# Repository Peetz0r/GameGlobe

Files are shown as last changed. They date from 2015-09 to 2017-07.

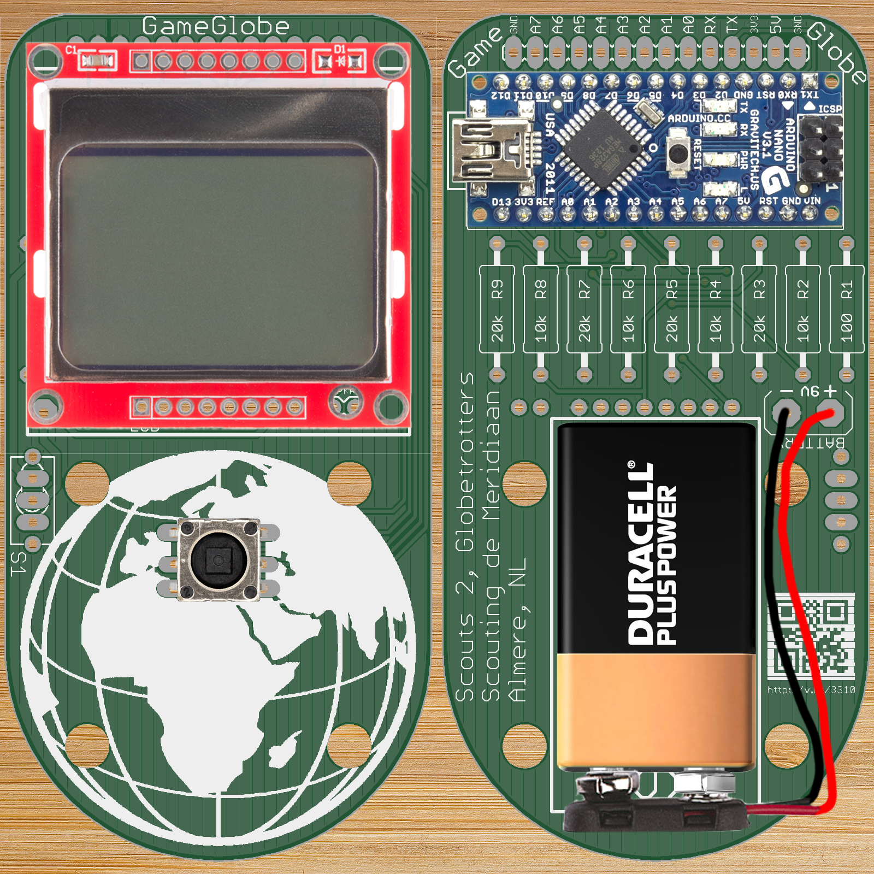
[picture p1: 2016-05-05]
pcb/gameglobe.png

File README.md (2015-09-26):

# GameGlobe
GameGlobe cheap handheld game console, Arduino based

# Bill Of Materials
Part			|  Price	|  Amount	|  Cost p.p.	|  Link
------------------------|--------------:|--------------:|--------------:|------------------------------
PCB			|  $28,00	|    20		|  $1,40	|  http://dirtypcbs.com/
Arduino Nano		|  $ 1,87	|     1		|  $1,87	|  http://www.aliexpress.com/item//32242060255.html
3310 display		|  $ 3,07	|     2		|  $1,54	|  http://www.aliexpress.com/item//32438248013.html
9V clip			|  $ 1,25	|    20		|  $0,06	|  http://www.aliexpress.com/item//32353434826.html
D-Pad (SKQUCAA010)	|  $10,93	|    20		|  $0,55	|  http://www.aliexpress.com/item//32354178656.html
Power switch		|  $ 3,50	|   100		|  $0,04	|  http://www.aliexpress.com/item//32390211893.html
Speaker			|  $ 6,18	|    50		|  $0,13	|  http://www.aliexpress.com/item//32438430293.html
Resistors		|    free	|  many		|   free	|  

Total $5,43

Note: somehow 20 boards is cheaper per piece than 30. So we'll buy 40 (2*20).
And the displays have some shipping costs (but they are the cheapest regardless).

Note: check all of the parts for hidden shippig costs when you order larger numbers.
It may be that a seller changes this without me knowing. Especially some of the Arduino sellers.

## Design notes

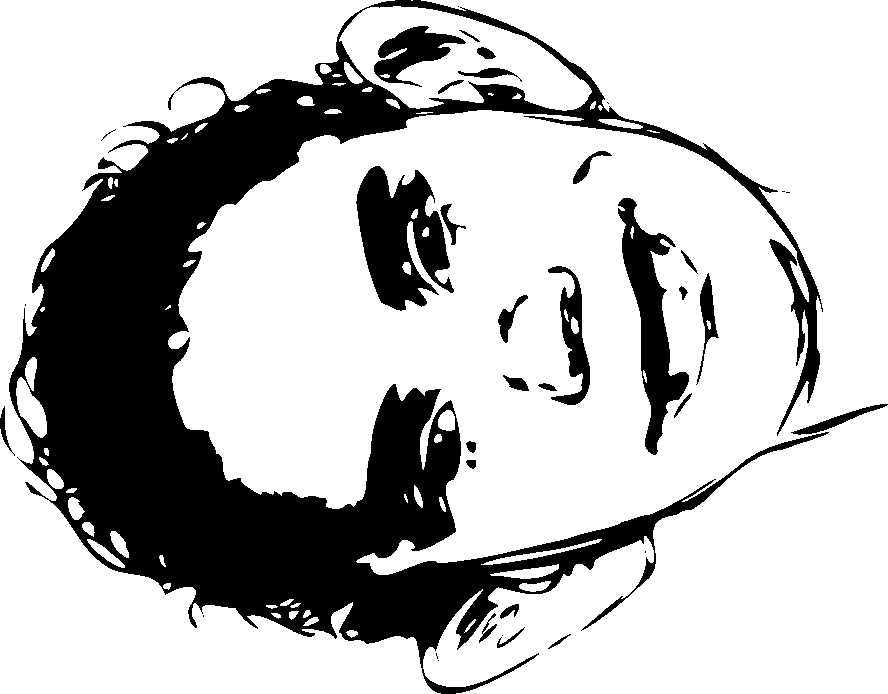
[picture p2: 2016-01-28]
pula-05-bw.bmp

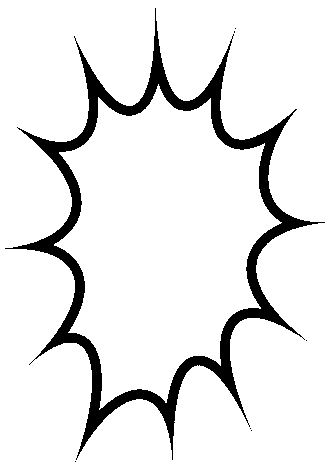
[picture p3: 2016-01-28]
boom.bmp

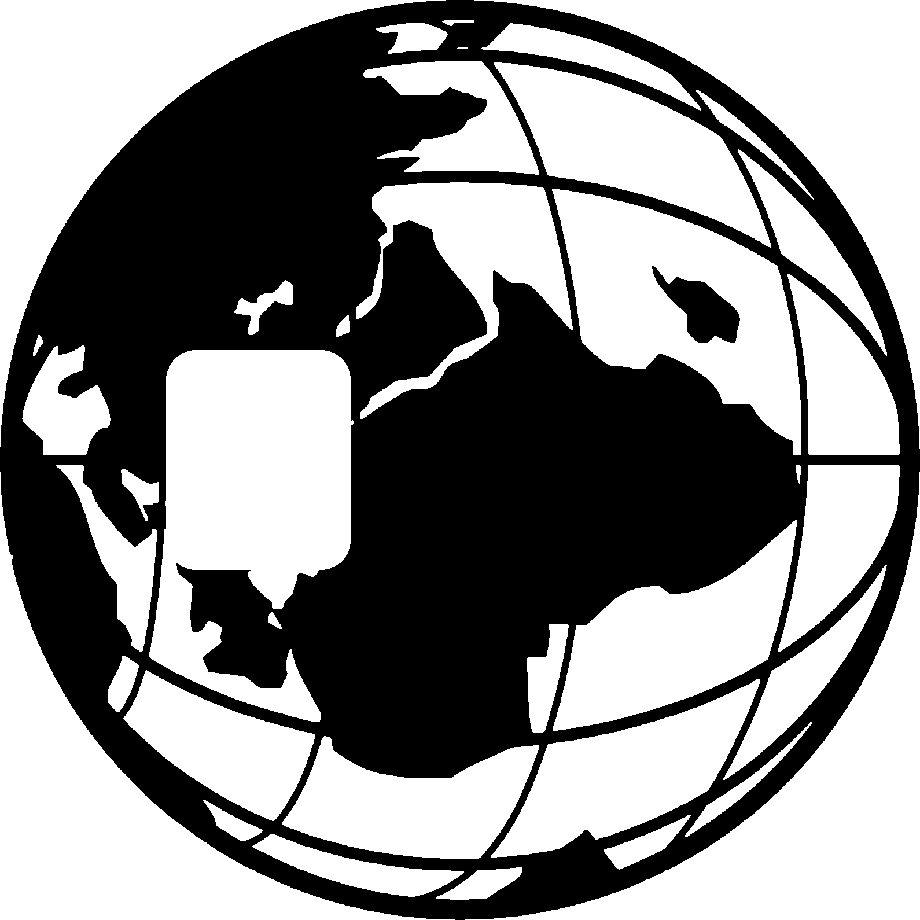
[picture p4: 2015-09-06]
wereldbol_silkscreen.bmp

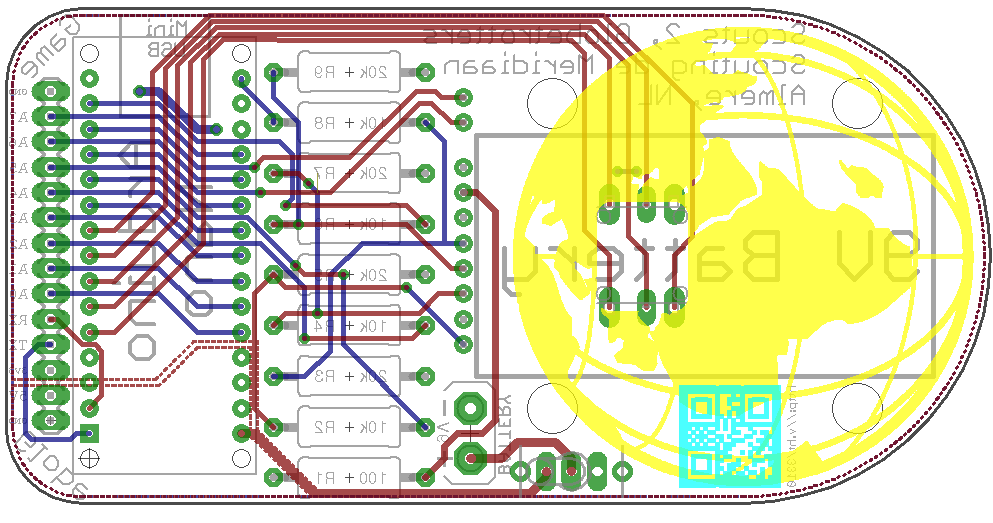
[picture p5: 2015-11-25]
pcb/pcb_layout.png

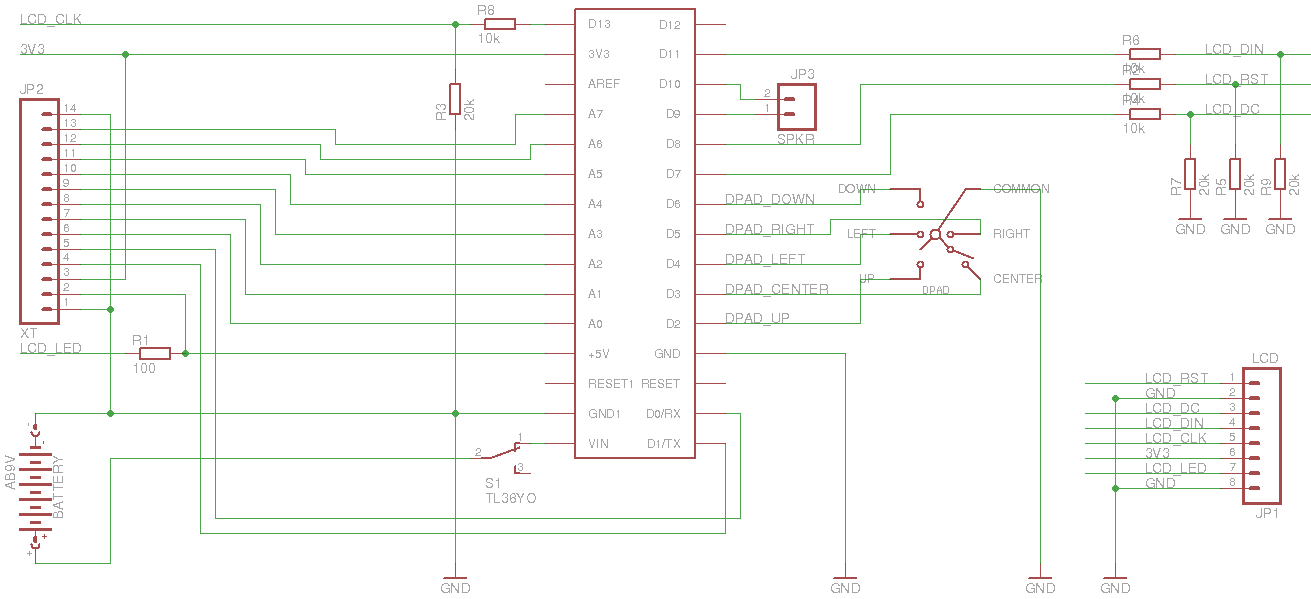
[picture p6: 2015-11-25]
pcb/schema.png

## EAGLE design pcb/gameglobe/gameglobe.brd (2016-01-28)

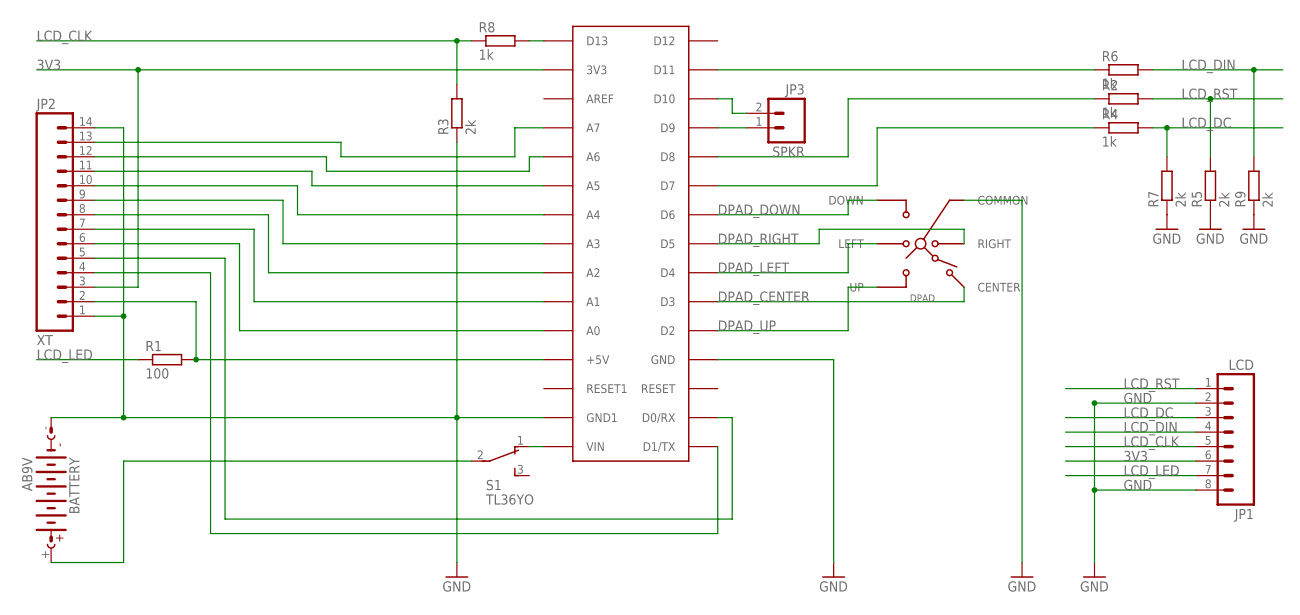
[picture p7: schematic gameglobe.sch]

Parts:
ARDUINO_NANO: ARDUINONANO; PDIP-32
BATTERY: AB9V
DPAD: SKQUCAA010; SKQU
JP1: LCD; 1X08_ROUND
JP2: XT; 1X14-LONGPADS
JP3: SPKR; 1X02
R1: 100; 0411/15
R2, R4, R6, R8: 1k; 0411/15
R3, R5, R7, R9: 2k; 0411/15
S1: TL36YO; TL3XYO

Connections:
3V3: ARDUINO_NANO.3V3, JP1.6, JP2.3
5V: ARDUINO_NANO.+5V, JP2.2, R1.2
A0: ARDUINO_NANO.A0, JP2.6
A1: ARDUINO_NANO.A1, JP2.7
A2: ARDUINO_NANO.A2, JP2.8
A3: ARDUINO_NANO.A3, JP2.9
A4: ARDUINO_NANO.A4, JP2.10
A5: ARDUINO_NANO.A5, JP2.11
A6: ARDUINO_NANO.A6, JP2.12
A7: ARDUINO_NANO.A7, JP2.13
DPAD_CENTER: ARDUINO_NANO.D3, DPAD.CENTER
DPAD_DOWN: ARDUINO_NANO.D6, DPAD.DOWN
DPAD_LEFT: ARDUINO_NANO.D4, DPAD.LEFT
DPAD_RIGHT: ARDUINO_NANO.D5, DPAD.RIGHT
DPAD_UP: ARDUINO_NANO.D2, DPAD.UP
GND: ARDUINO_NANO.GND, ARDUINO_NANO.GND1, BATTERY.-, DPAD.COMMON, JP1.2, JP1.8, JP2.1, JP2.14, R3.1, R5.1, R7.1, R9.1
LCD_CLK: JP1.5, R3.2, R8.1
LCD_DC: JP1.3, R4.2, R7.2
LCD_DIN: JP1.4, R6.2, R9.2
LCD_LED: JP1.7, R1.1
LCD_RST: JP1.1, R2.2, R5.2
unnamed: ARDUINO_NANO.D13, R8.2
unnamed: ARDUINO_NANO.D11, R6.1
unnamed: ARDUINO_NANO.D8, R2.1
unnamed: ARDUINO_NANO.D9, JP3.1
unnamed: ARDUINO_NANO.VIN, S1.1 (O)
unnamed: BATTERY.+, S1.2
unnamed: ARDUINO_NANO.D10, JP3.2
unnamed: ARDUINO_NANO.D7, R4.1
RX: ARDUINO_NANO.D0/RX, JP2.5
TX: ARDUINO_NANO.D1/TX, JP2.4

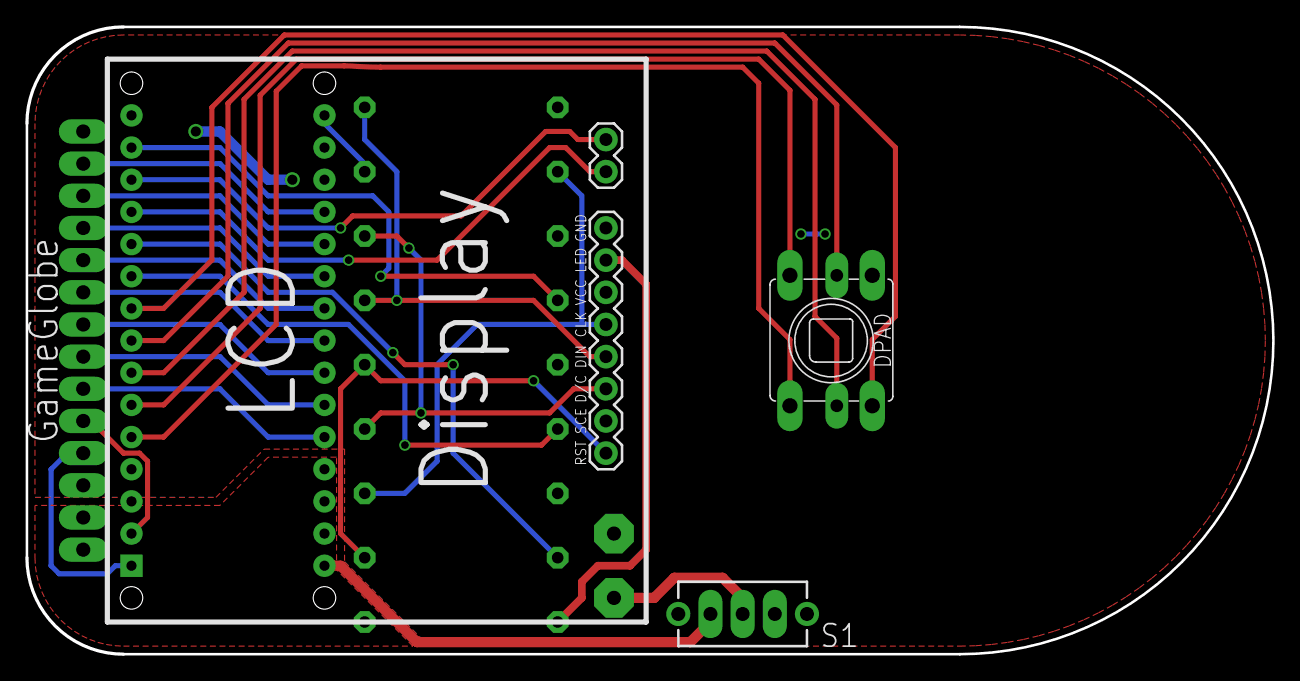
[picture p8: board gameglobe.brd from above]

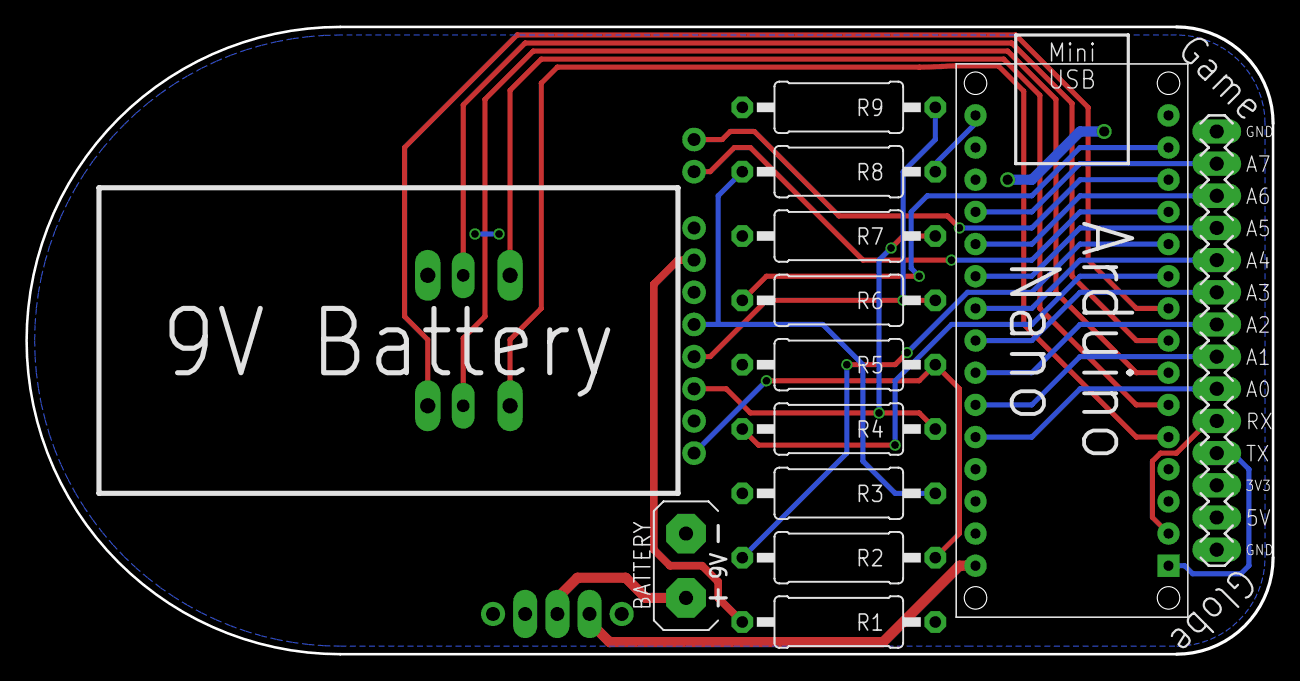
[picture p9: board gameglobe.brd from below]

Board: 2 copper layers, 98.4 x 49.5 mm, 16 parts (12 on the bottom side), 31 nets.

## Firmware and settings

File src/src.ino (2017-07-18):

#include "../lib/Adafruit-GFX-Library/Adafruit_GFX.h"
#include "../lib/Adafruit_PCD8544.h"
#include "../lib/Bounce2/Bounce2.h"
#include "../lib/arduino-toneac/toneAC.h"
#include <EEPROM.h>
#include "pitches.h"
#include "naam.h"

#define PIN_U 2
#define PIN_S 3
#define PIN_L 4
#define PIN_R 5
#define PIN_D 6

#define PIN_LCD_DC  7
#define PIN_LCD_RST 8

#define EEPROM_VOLUME 10
#define EEPROM_SNAKE 110
#define EEPROM_TETRIS 120
#define EEPROM_FLAPPY 130

Adafruit_PCD8544 d = Adafruit_PCD8544(PIN_LCD_DC, -1, PIN_LCD_RST);

Bounce b_u = Bounce();
Bounce b_d = Bounce();
Bounce b_l = Bounce();
Bounce b_r = Bounce();
Bounce b_s = Bounce();

enum game {
	MENU,
	SNAKE,
	TETRIS,
	FLAPPY,
	HIGHSCORES,
	GAME_OVER,
};

game current_game = MENU;
game previous_game;

int8_t selected = 0;
uint8_t volume;
uint8_t need_write_volume = 0;
uint8_t score;

uint8_t snake_length;
uint8_t snake_pos[255];
int8_t snake_food_x;
int8_t snake_food_y;
long snake_delay;
long snake_last_frame = 0;
enum direction {
	UP,
	DOWN,
	LEFT,
	RIGHT,
};
direction snake_direction = LEFT;
direction snake_direction_old = LEFT;

#define TETRIS_I1 0x00f0
#define TETRIS_I2 0x2222

#define TETRIS_J1 0x0047
#define TETRIS_J2 0x0322
#define TETRIS_J3 0x0071
#define TETRIS_J4 0x0113

#define TETRIS_L1 0x0017
#define TETRIS_L2 0x0223
#define TETRIS_L3 0x0074
#define TETRIS_L4 0x0311

#define TETRIS_O1 0x0033

#define TETRIS_S1 0x0036
#define TETRIS_S2 0x0231

#define TETRIS_T1 0x0027
#define TETRIS_T2 0x0232
#define TETRIS_T3 0x0072
#define TETRIS_T4 0x0131

#define TETRIS_Z1 0x0063
#define TETRIS_Z2 0x0132

uint8_t tetris_speed;
long tetris_delay;
long tetris_last_frame = 0;
uint16_t tetris_state[10];
int8_t tetris_tetromino_x;
int8_t tetris_tetromino_y;
uint16_t tetris_tetromino_shape;
uint16_t tetris_tetromino_next;

uint8_t flappy_x;
float flappy_y;
float flappy_y_speed;
int8_t flappy_pipe;
long flappy_delay;

void menu_loop() {
	d.clearDisplay();
	if(b_u.fell()) selected--;
	if(b_d.fell()) selected++;
	if(selected > 4) selected = 0;
	if(selected < 0) selected = 4;

	d.drawRoundRect(0,selected*9, 80,11, 5, 1);
	d.drawLine(1,selected*9+5, 6,selected*9+5, 1);
	d.fillTriangle(6,selected*9+3, 6,selected*9+7, 8,selected*9+5, 1);

	d.setCursor(11, 2);
	d.print("Snake");
	d.setCursor(11, 11);
	d.print("Tetris");
	d.setCursor(11, 20);
	d.print("FlappySmile");
	d.setCursor(11, 29);
	d.print("Highscores");
	d.setCursor(11, 38);

	d.print("Volume");
	d.drawRect(52,37,         24,9, 1);
	d.fillRect(54,39, (volume*2),5, 1);
	if(volume == 0) {
		d.drawLine(52,37, 75,45, 1);
		d.drawLine(52,45, 75,37, 1);
	}

	if(b_s.fell()) {
		toneAC(NOTE_A6, volume, 25);
		score = 0;
		if(selected == 0) {
			snake_length = 5;
			snake_pos[0] = 115;
			snake_pos[1] = 116;
			snake_pos[2] = 117;
			snake_pos[3] = 118;
			snake_pos[4] = 119;
			snake_delay = 350;
			snake_last_frame = 0;
			snake_direction = LEFT;
			snake_place_food();

			current_game = SNAKE;
		} else if(selected == 1) {
			tetris_state[0] = 0;
			tetris_state[1] = 0;
			tetris_state[2] = 0;
			tetris_state[3] = 0;
			tetris_state[4] = 0;
			tetris_state[5] = 0;
			tetris_state[6] = 0;
			tetris_state[7] = 0;
			tetris_state[8] = 0;
			tetris_state[9] = 0;

			tetris_speed = 1;
			tetris_delay = 500;
			tetris_last_frame = 0;

			current_game = TETRIS;
		} else if(selected == 2) {
			flappy_x = 0;
			flappy_y = 24;
			flappy_y_speed = 0;
			flappy_pipe = 12;
			flappy_delay = 50;

			current_game = FLAPPY;
		} else if(selected == 3) {
			current_game = HIGHSCORES;
		}
	}

	if(selected == 4) {
		if(b_l.fell()) {
			if(volume > 0) {
				volume--;
				need_write_volume = 1;
			}
			toneAC(NOTE_A6, volume, 25);
		}
		if(b_r.fell()) {
			if(volume < 10) {
				volume++;
				need_write_volume = 1;
			}
			toneAC(NOTE_A6, volume, 25);
		}
	} else if(need_write_volume == 1) {
		EEPROM.write(EEPROM_VOLUME, volume);
		need_write_volume = 0;
	}

	d.display();
	delay(25);
}

void snake_loop () {
	if(b_u.fell() && snake_direction_old != DOWN ) snake_direction = UP;
	if(b_d.fell() && snake_direction_old != UP   ) snake_direction = DOWN;
	if(b_l.fell() && snake_direction_old != RIGHT) snake_direction = LEFT;
	if(b_r.fell() && snake_direction_old != LEFT ) snake_direction = RIGHT;

	if((millis() - snake_last_frame) > snake_delay) {
		snake_direction_old = snake_direction;
		d.clearDisplay();

		for(uint8_t i = snake_length+1; i > 0; i--) {
			snake_pos[i] = snake_pos[i-1];
		}

		int8_t tmp_snake_x;
		int8_t tmp_snake_y;

		switch(snake_direction) {
			case UP:
				tmp_snake_x = (snake_pos[1]%21);
				tmp_snake_y = (snake_pos[1]/21)-1;
				break;
			case DOWN:
				tmp_snake_x = (snake_pos[1]%21);
				tmp_snake_y = (snake_pos[1]/21)+1;
				break;
			case LEFT:
				tmp_snake_x = (snake_pos[1]%21)-1;
				tmp_snake_y = (snake_pos[1]/21);
				break;
			case RIGHT:
				tmp_snake_x = (snake_pos[1]%21)+1;
				tmp_snake_y = (snake_pos[1]/21);
				break;
		}

		if(tmp_snake_x <  0) tmp_snake_x = 20;
		if(tmp_snake_x > 20) tmp_snake_x =  0;
		if(tmp_snake_y <  0) tmp_snake_y = 11;
		if(tmp_snake_y > 11) tmp_snake_y =  0;


		snake_pos[0] = tmp_snake_y*21 + tmp_snake_x;

		if(tmp_snake_x == snake_food_x && tmp_snake_y == snake_food_y) {
			snake_length++;
			snake_place_food();
			snake_delay *= 0.975; // snake difficulty

			toneAC(NOTE_G5, volume, 40); delay(20);
			toneAC(NOTE_G6, volume, 40);
		} else {
			toneAC(NOTE_A3, volume, 5);
		}

		for(uint8_t i = 0; i < snake_length; i++) {
			d.fillRoundRect((snake_pos[i]%21)*4, (snake_pos[i]/21)*4, 4, 4, 1, 1);
			if(i > 0 && tmp_snake_x == snake_pos[i]%21 && tmp_snake_y == snake_pos[i]/21) {
				score = snake_length;
				previous_game = SNAKE;
				game_over();
			}
		}
		d.drawRoundRect(snake_food_x*4, snake_food_y*4, 4, 4, 2, 1);
		d.display();

		snake_last_frame = millis();
	}
}

void snake_place_food() {
	boolean done = false;
	while(!done) {
		snake_food_x = random(20);
		snake_food_y = random(11);
		done = true;
		for(uint8_t i = 0; i < snake_length; i++) {
			if(snake_food_x == snake_pos[i]%21 && snake_food_y == snake_pos[i]/21) {
				done = false;
			}
		}
	}
}

uint16_t tetris_new_shape() {
	uint16_t shape;
	switch (random(7)) {
		case 0: shape = TETRIS_I1; break;
		case 1: shape = TETRIS_J1; break;
		case 2: shape = TETRIS_L1; break;
		case 3: shape = TETRIS_O1; break;
		case 4: shape = TETRIS_S1; break;
		case 5: shape = TETRIS_T1; break;
		case 6: shape = TETRIS_Z1; break;
	}
	for(int i = random(4); i >= 0; i--) {
		shape = tetris_rotate(shape);
	}
	return shape;
}

uint16_t tetris_rotate(uint16_t shape) {
	switch(shape) {
		case TETRIS_I1: return TETRIS_I2;
		case TETRIS_I2: return TETRIS_I1;

		case TETRIS_J1: return TETRIS_J2;
		case TETRIS_J2: return TETRIS_J3;
		case TETRIS_J3: return TETRIS_J4;
		case TETRIS_J4: return TETRIS_J1;

		case TETRIS_L1: return TETRIS_L2;
		case TETRIS_L2: return TETRIS_L3;
		case TETRIS_L3: return TETRIS_L4;
		case TETRIS_L4: return TETRIS_L1;

		case TETRIS_O1: return TETRIS_O1;

		case TETRIS_S1: return TETRIS_S2;
		case TETRIS_S2: return TETRIS_S1;

		case TETRIS_T1: return TETRIS_T2;
		case TETRIS_T2: return TETRIS_T3;
		case TETRIS_T3: return TETRIS_T4;
		case TETRIS_T4: return TETRIS_T1;

		case TETRIS_Z1: return TETRIS_Z2;
		case TETRIS_Z2: return TETRIS_Z1;
	}
}

void tetris_loop () {
	if((millis() - tetris_last_frame) > tetris_delay / tetris_speed) {

		toneAC(NOTE_A3, volume, 5);
		if(!tetris_tetromino_shape) {
			if(!tetris_tetromino_next) {
				tetris_tetromino_next = tetris_new_shape();
			}
			tetris_tetromino_shape = tetris_tetromino_next;
			tetris_tetromino_next = tetris_new_shape();
			tetris_tetromino_x = 4;
			tetris_tetromino_y = -1;
			tetris_speed = 1;
		}

		tetris_draw(0, 1);

		tetris_last_frame = millis();
	}

	if(b_d.fell()) {
		tetris_speed = 10;
	}
	if(b_d.rose()) {
		tetris_speed = 1;
	}

	if(b_l.fell()) {
		tetris_draw(-1, 0);
	}
	if(b_r.fell()) {
		tetris_draw(1, 0);
	}

	if(b_u.fell()) {
		tetris_tetromino_shape = tetris_rotate(tetris_tetromino_shape);
		tetris_draw(0, 0);
	}
}

void tetris_draw(int m_x, int m_y) {
	d.clearDisplay();
	d.drawRect(11, -1, 31, 49, 1);

	int tetris_move_ok = 1;

	for(int t_x = 0; t_x < 4; t_x++) {
		for(int t_y = 0; t_y < 4; t_y++) {
			if(tetris_tetromino_shape & (1 << (t_y*4+t_x))) {
				if(tetris_tetromino_y+m_y+t_y > 15
				 || (tetris_state[tetris_tetromino_x+m_x+t_x] >> tetris_tetromino_y+m_y+t_y) & 1
				 || tetris_tetromino_x+m_x+t_x > 9
				 || tetris_tetromino_x+m_x+t_x < 0) {

					 if(m_x == 0 && m_y == 0) {
						for(int i = 0; i < 3; i++) {
							tetris_tetromino_shape = tetris_rotate(tetris_tetromino_shape);
						}
					 }

					if(tetris_tetromino_y < 1) {
						previous_game = TETRIS;
						game_over();
						return;
					}

					if(m_y) {
						for(int x2 = 0; x2 < 4; x2++) {
							for(int y2 = 0; y2 < 4; y2++) {
								if(tetris_tetromino_shape & (1 << (y2*4+x2))) {
									tetris_state[tetris_tetromino_x+m_x+x2] |= 1 << (tetris_tetromino_y+y2);
								}
							}
						}
						tetris_tetromino_shape = 0;

						int points = 0;
						for(int i = 0; i < 16; i++) {
							int test = 1;
							for(int j = 0; j < 10; j++) {
								test &= (tetris_state[j] >> i) &1;
							}
							if(test) {
								if(!points) {
									points = 1;
								} else {
									points *= 2;
								}
								Serial.println(i);

								for(int j = 0; j < 10; j++) {
									uint16_t mask_r = (1 << i+1)-1;
									uint16_t mask_l = ~mask_r;
									tetris_state[j] = (tetris_state[j]&mask_l) | (tetris_state[j]&mask_r>>1) << 1;
								}

								i--;

								// beep!
								toneAC(NOTE_G5, volume, 40); delay(20);
								toneAC(NOTE_G6, volume, 40);
							}
						}
						score += points;

						tetris_delay *= 0.985; // tetris difficulty (should be closer to 1 than snake)

					}
					tetris_move_ok = 0;
				}
			}
		}
	}

	if(tetris_move_ok) {
		tetris_tetromino_x += m_x;
		tetris_tetromino_y += m_y;
	}

	for(int t_x = 0; t_x < 4; t_x++) {
		for(int t_y = 0; t_y < 4; t_y++) {
			if(tetris_tetromino_shape & (1 << (t_y*4+t_x))) {
				d.fillRect(12+(tetris_tetromino_x+t_x)*3, (tetris_tetromino_y+t_y)*3, 2, 2, 1);
			}
		}
	}

	for(int x = 0; x < 10; x++) {
		for(int y = 0; y < 16; y++) {
			if(tetris_state[x] & (1 << y)) {
					d.fillRect(12+x*3, y*3, 2, 2, 1);
			}
		}
	}

	for(int t_x = 0; t_x < 4; t_x++) {
		for(int t_y = 0; t_y < 4; t_y++) {
			if(tetris_tetromino_next & (1 << (t_y*4+t_x))) {
				d.fillRect(60+t_x*3, 6+t_y*3, 2, 2, 1);
			}
		}
	}

	d.setCursor(49, 26);
	d.print("Score");
	d.setCursor(55, 36);
	d.print(score);

	d.display();
}

void flappy_loop () {
	flappy_y += flappy_y_speed;

	// generate new pipes once in a while
	if(flappy_x > 120) {
		flappy_x = 0;
		flappy_pipe = random(24);
	}

	// change vertical acceleration over time
	if(flappy_y_speed < 0) {
		// when moving up, decelerate quickly
		flappy_y_speed += 0.2;
	} else {
		// when falling down, accelerate less quickly
		flappy_y_speed += 0.075;
	}

	// (re)set vertical acceleration on button push
	if(b_u.fell()) {
		flappy_y_speed = -2;
	}

	// collision checking
	if(flappy_y > 47 ||
	  ((flappy_x > 52 && flappy_x < 68) &&
	  (flappy_y < flappy_pipe+8 || flappy_y > flappy_pipe+20))) {
		previous_game = FLAPPY;
		game_over();
	}

	if(flappy_x == 70) {
		score++;
		flappy_delay *= 0.975;
	}

	flappy_x++;

	d.clearDisplay();

	// pipes, narrow part
	d.fillRect(100-flappy_x, 0, 10, flappy_pipe, 1); // upper
	d.fillRect(100-flappy_x, flappy_pipe+28, 10, 100, 1); // lower

	// pipes, wide part (edge)
	d.fillRect(100-flappy_x-2, flappy_pipe-2, 14, 4, 1); // upper
	d.fillRect(100-flappy_x-2, flappy_pipe+26, 14, 4, 1); // lower

	d.drawCircle(42, flappy_y-1, 5, 1); // face
	d.fillRect(39, flappy_y-3, 2, 2, 1); // left eye
	d.fillRect(44, flappy_y-3, 2, 2, 1); // right eye
	d.drawLine(39, flappy_y, 41, flappy_y+2, 1); // left part of smile
	d.drawPixel(42, flappy_y+2, 1); // center part of smile
	d.drawLine(43, flappy_y+2, 45, flappy_y, 1); // right part of smile
	d.display();

	delay(flappy_delay);
}

void game_over() {
	current_game = GAME_OVER;

	toneAC(NOTE_G6, volume, 50);
	toneAC(NOTE_F6, volume, 50);
	toneAC(NOTE_E6, volume, 50);
	toneAC(NOTE_D6, volume, 50);
	toneAC(NOTE_C6, volume, 50);
	toneAC(NOTE_B6, volume, 50);
	toneAC(NOTE_A6, volume, 50);
	toneAC(NOTE_G5, volume, 50);
	toneAC(NOTE_F5, volume, 50);
	toneAC(NOTE_E5, volume, 50);
	toneAC(NOTE_D5, volume, 50);
	toneAC(NOTE_C5, volume, 50);
	toneAC(NOTE_B5, volume, 50);
	toneAC(NOTE_A5, volume, 50);
	toneAC(NOTE_G4, volume, 50);
	toneAC(NOTE_F4, volume, 50);
	toneAC(NOTE_E4, volume, 50);
	toneAC(NOTE_D4, volume, 50);
	toneAC(NOTE_C4, volume, 50);
	toneAC(NOTE_B4, volume, 50);
	toneAC(NOTE_A4, volume, 50);
	toneAC(NOTE_G3, volume, 50);
	toneAC(NOTE_F3, volume, 50);
	toneAC(NOTE_E3, volume, 50);
	toneAC(NOTE_D3, volume, 50);
	toneAC(NOTE_C3, volume, 50);
	toneAC(NOTE_B3, volume, 50);
	toneAC(NOTE_A3, volume, 50);
	toneAC(NOTE_G2, volume, 50);
	toneAC(NOTE_F2, volume, 50);
	toneAC(NOTE_E2, volume, 50);
	toneAC(NOTE_D2, volume, 50);
	toneAC(NOTE_C2, volume, 50);
	toneAC(NOTE_B2, volume, 50);
	toneAC(NOTE_A2, volume, 50);
	toneAC(NOTE_G1, volume, 50);
	toneAC(NOTE_F1, volume, 50);
	toneAC(NOTE_E1, volume, 50);
	toneAC(NOTE_D1, volume, 50);
	toneAC(NOTE_C1, volume, 50);
	toneAC(NOTE_B1, volume, 50);
	toneAC(NOTE_A1, volume, 50);
}

void game_over_loop() {
	d.clearDisplay();
	d.setCursor(0, 0);
	d.setTextSize(2);
	d.print("GAME");
	d.setCursor(36, 12);
	d.print("OVER");

	d.setTextSize(1);
	d.setCursor(0, 30);
	d.print("Your score");
	d.setCursor(66, 30);
	d.print(score);

	int address;

	switch(previous_game) {
		case SNAKE:       address = EEPROM_SNAKE;       break;
		case TETRIS:      address = EEPROM_TETRIS;      break;
		case FLAPPY: address = EEPROM_FLAPPY; break;
	}

	byte highscore = EEPROM.read(address);
	if(score > highscore || highscore == 255) {
		highscore = score;
		EEPROM.write(address, highscore);
	}

	d.setCursor(0, 40);
	d.print("High score");
	d.setCursor(66, 40);
	d.print(highscore);

	d.display();

	if(b_s.fell()) current_game = MENU;

	delay(25);
}

void highscores_loop() {
	d.clearDisplay();

	uint8_t highscore;

	d.setCursor(0, 0);
	d.print("High scores:");

	d.setCursor(0, 16);
	d.print("Snake");
	highscore = EEPROM.read(EEPROM_SNAKE);
	if(highscore < 10) {
		d.setCursor(78, 16);
		d.print(highscore);
	} else if(highscore < 100) {
		d.setCursor(72, 16);
		d.print(highscore);
	} else if(highscore < 255) {
		d.setCursor(66, 16);
		d.print(highscore);
	}

	d.setCursor(0, 26);
	d.print("Tetris");
	highscore = EEPROM.read(EEPROM_TETRIS);
	if(highscore < 10) {
		d.setCursor(78, 26);
		d.print(highscore);
	} else if(highscore < 100) {
		d.setCursor(72, 26);
		d.print(highscore);
	} else if(highscore < 255) {
		d.setCursor(66, 26);
		d.print(highscore);
	}

	d.setCursor(0, 36);
	d.print("Flappy");
	highscore = EEPROM.read(EEPROM_FLAPPY);
	if(highscore < 10) {
		d.setCursor(78, 36);
		d.print(highscore);
	} else if(highscore < 100) {
		d.setCursor(72, 36);
		d.print(highscore);
	} else if(highscore < 255) {
		d.setCursor(66, 36);
		d.print(highscore);
	}

	d.display();

	if(b_s.fell()) current_game = MENU;

	delay(25);
}

void setup() {
	randomSeed(analogRead(A0));

	Serial.begin(115200); // FIXME: debug!

	volume = EEPROM.read(EEPROM_VOLUME);
	if(volume >10) {
		volume = 5;
	}

	toneAC(NOTE_A4, volume, 50);

	pinMode(PIN_L, INPUT_PULLUP);
	pinMode(PIN_R, INPUT_PULLUP);
	pinMode(PIN_D, INPUT_PULLUP);
	pinMode(PIN_U, INPUT_PULLUP);
	pinMode(PIN_S, INPUT_PULLUP);

	b_u.attach(PIN_U);
	b_d.attach(PIN_D);
	b_l.attach(PIN_L);
	b_r.attach(PIN_R);
	b_s.attach(PIN_S);

	b_u.interval(20);
	b_d.interval(20);
	b_l.interval(20);
	b_r.interval(20);
	b_s.interval(20);

	d.begin();
	d.setContrast(55);

	d.clearDisplay();
	d.setCursor(30, 2);
	d.print("Deze");
	d.setCursor(15, 10);
	d.print("GameGlobe");
	d.setCursor(21, 18);
	d.print("is van:");
	if(sizeof(NAAM) <= 8) {
		d.setTextSize(2);
		d.setCursor(int(42-(sizeof(NAAM)-1)*6), 32);
		d.print(NAAM);
		d.setTextSize(1);
	} else {
		d.setCursor(int(42-(sizeof(NAAM)-1)*3), 36);
		d.print(NAAM);
	}
	d.display();

	toneAC(NOTE_A5, volume, 100);
	delay(300);

	toneAC(NOTE_A5, volume, 50);
	delay(100);

	toneAC(NOTE_A5, volume, 200);
	delay(2000);
}

void loop() {
	b_u.update();
	b_d.update();
	b_l.update();
	b_r.update();
	b_s.update();

	if(current_game == MENU) {
		menu_loop();
	} else if(current_game == SNAKE) {
		snake_loop();
	} else if(current_game == TETRIS) {
		tetris_loop();
	} else if(current_game == FLAPPY) {
		flappy_loop();
	} else if(current_game == HIGHSCORES) {
		highscores_loop();
	} else if(current_game == GAME_OVER) {
		game_over_loop();
	}
}

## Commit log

2015-08-23 add initial schematic an board very early version
    [gameglobe.brd, gameglobe.sch]
2015-08-24 BOM is sortof complete, and PCB is more complete-ish now
    [gameglobe.brd, gameglobe.sch]
2015-08-28 Add backlight wire and resistor
    [gameglobe.brd, gameglobe.sch]
2015-08-28 Create inotools setup Add Adafruit libraries Create basic sketch (which doesn't do anything really)
    [sketch.ino]
2015-08-28 Improve net names and board layout
    [gameglobe.brd, gameglobe.sch]
2015-08-28 Update BOM with less parts and cheaper and better PCBs
2015-08-29 Updated DRU file; Improved PCB layout; Added rounded edges and mount holes
    [gameglobe.brd, gameglobe.sch]
2015-08-30 More PCB improvements, moved the Nano a bit sideways and improved battery mounting holes
    [gameglobe.brd]
2015-08-30 Many PCB improvements. Actually the first version where everything (joystick, lcd, nano) is centered on the board
    [gameglobe.brd, gameglobe.sch]
2015-08-30 Fix and add own arduino Improve silkscreen texts
    [gameglobe.brd, gameglobe.sch]
2015-08-30 Added LCD Display outline
    [gameglobe.brd]
2015-08-30 Neated-up scheme
    [gameglobe.sch]
2015-08-30 Improved silkscreen
    [gameglobe.brd, gameglobe.sch]
2015-08-30 Reverse button logic
2015-09-01 Added power switch to pcb. LCD pin labels on slikscreen
    [gameglobe.brd, gameglobe.sch]
2015-09-01 Update list of parts to include power switch
2015-09-02 Set LED resistor value to 100 (after testing with prototype); Move some silkscreen items around; Enable all needed layers in Eagle
    [gameglobe.brd, gameglobe.sch]
2015-09-04 Almost complete snake implementation with some memory issues
    [sketch.ino]
2015-09-06 Fixed snake issues; Finished snake; Implemented basic highscore system;
    [sketch.ino]
2015-09-06 Made awesome silkscreen art
    [gameglobe.brd]
2015-09-06 Changed to cheaper speaker (flat piezo buzzer); Mount speaker belof display, add connector for speaker; Improve 9V connector; Improve silkscreen again;
    [gameglobe.brd, gameglobe.sch]
2015-09-07 Reduced silkscreen text size
    [gameglobe.brd]
2015-09-08 Add QR code; Reduce top corner radiuses; Fix/improve some routing things;
    [gameglobe.brd]
2015-09-23 change wiring to use different pins for the speaker with ToneAC library (and also all the buttons)
    [gameglobe.brd, gameglobe.sch]
2015-09-23 Use toneAC, also change pin numbers everywhere
2015-09-23 change pin numbers (just as in the code, see previous commit), also use ground plane
    [gameglobe.brd, gameglobe.sch]
2015-09-24 Add power planes for 3V3 and 5V to add a more premium feeling to the board design (whatever this may mean)
    [gameglobe.brd, gameglobe.sch]
2015-09-24 Improved power plane layout, also improved silkscreen, updated mockup image with new pcb renders
    [gameglobe.brd, gameglobe.sch]
2015-09-24 Increased pad sizes, swapped DPAD left/right pins for better routing, improved silkscreen text
    [gameglobe.brd, gameglobe.sch]
2015-09-25 Got my arduino elsewhere (because they suddenly added shipping)
2015-09-25 Rotate part in schematic for neater layout, pcb unchanged
    [gameglobe.sch]
2015-09-25 Add volume with memory and menu display, fix reset pin, change eeprom addresses
    [sketch.ino]
2015-09-26 Resistor renaming and related silkscreen fixes
    [gameglobe.brd, gameglobe.sch]
2015-09-26 Changed Arduino seller again, because of shipping costs
2015-09-30 Make multiple button presses not stack ytogether in one frame. The old behaviour was that, when moving left, and pressing 'up' and 'right' quickly after eachother, would kill the snake. now it doesn'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
    [sketch.ino]
2016-01-28 New generic silkscreen design
    [gameglobe.brd, gameglobe.sch]
2016-02-16 ano support (ano is a fork of inotool, compatible with newer arduino ide versions)
2016-03-29 Replaced qr code splash screen (which was unscannable) with a personalised splash screen stating the name of the owner
    You can flash this with "./nameflash.sh YourName"
    Names up to 14 characters are supported
    [sketch.ino]
2016-04-08 Basics of tetris working. no scoring, and very broken colission detection
    [sketch.ino]
2016-05-05 Changed PCB supplier (pcb color) from blue to read, removed QR code from mockup image
2016-05-05 binary game logic bug fixed
    the bug caused the game to remove not only the correct line but all lines below it as well
    [sketch.ino]
2016-05-05 believe it or not, this saves 1084 bytes of arduino space
2017-07-18 make it arduino-ide-compatible again. I probably broke ano/ino compatibility right now
    [src.ino]

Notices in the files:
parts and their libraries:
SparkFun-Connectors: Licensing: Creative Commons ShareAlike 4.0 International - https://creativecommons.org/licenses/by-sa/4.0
